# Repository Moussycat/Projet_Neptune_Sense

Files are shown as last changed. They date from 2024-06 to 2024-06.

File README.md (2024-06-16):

# Project_Neptune_Sense

### Projet de synthèse objets connectés

#### Semestre 8 - Option Electronique et Objets connectés ESEO

Notre système se compose de deux modules complémentaires. Il est conçu pour simplifier la gestion de votre espace aquatique tout en garantissant une qualité d'eau optimale

Le premier module, autonome en énergie, est spécialement conçu pour résister aux conditions extérieures. Équipé de capteurs de pointe, il collecte en temps réel les informations essentielles à la bonne gestion de votre piscine. Mesurez avec précision le pH de l'eau, sa température ainsi que celle de l'air ambiant, pour une expérience de baignade toujours agréable. De plus, ce module est doté d'un indicateur de niveau de batterie, vous assurant ainsi une utilisation continue et sans souci.

Le second module, alimenté par le secteur, est votre station de base. Il reçoit et traite toutes les données transmises par le module extérieur. Grâce à son interface intuitive, accédez facilement à toutes les informations relatives à votre piscine, et ce, en un seul endroit.

Ce projet, alliant technologie et praticité, vous offre une solution pour une gestion simplifiée de votre piscine ou bassin.

## Description

Pour que vous puissiez mieux appréhender la logique et les choix qui ont guidé notre projet, nous vous fournissons quelques éléments d'information essentiels. Parmi ces documents, se trouve le [cahier des charges](Cahier_des_charges.pdf) qui définit les objectifs, les contraintes et les exigences auxquelles notre projet doit répondre ainsi que le [schéma synoptique](Schema_synoptique_Neptune_Sense.pdf), qui présente de manière graphique l'ensemble des systèmes pour une vue générale du projet.

### [Code](Code/README.md)

#### [Station de base](Code/main_station_base/)

Cette station s'installe dans un bâtiment où elle pourra avoir accès à un réseau internet. La station permet d'afficher sur un écran TFT la température de l'eau et de l'air, le PH de votre bassin, le niveau de l'eau, le niveau de batterie de la station extérieure, l'horloge et la météo.

#### [Station extérieure](Code/CODE%20NeptuneSense/)

Cette station se met à proximité de votre bassin. La sonde de PH, le capteur de température d'eau et le niveau de l'eau doivent être placé dans l'eau. Le dispositif doit être à proximité d'une station de réception Lora public.

### [PCB](PCB/README.md)

Au cours de notre projet, nous avons élaboré et fabriqué deux cartes de circuits imprimés (PCB) bien distinctes. La première d'entre elles est destinée à la station de base, tandis que la seconde est spécifiquement conçue pour la station extérieure. Il convient de souligner que ces deux PCB sont équipées de microcontrôleurs différents, afin de répondre au mieux aux contraintes et aux exigences de chaque station. Pour en savoir plus sur ce sujet, nous vous invitons à cliquer sur le titre de la partie correspondante.

### [Tests](Tests/README.md)

Nous avons procédé à la réalisation de tests unitaires pour chacune des fonctions implémentées dans les deux stations. Ces tests ont pour objectif de vérifier le bon fonctionnement de chaque fonctionnalité de manière isolée. Les détails et les descriptions de ces tests sont disponibles dans les dossiers respectifs de chaque test, afin de faciliter la compréhension et la traçabilité des vérifications effectuées.

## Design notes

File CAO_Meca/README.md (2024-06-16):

# CAO 

### Station Exterieure :

Nous avons confectionner un socle pouvant acceuilir le PCB et laisser place à tous les parts tels que l'USB C, le port du capteur PH etc.

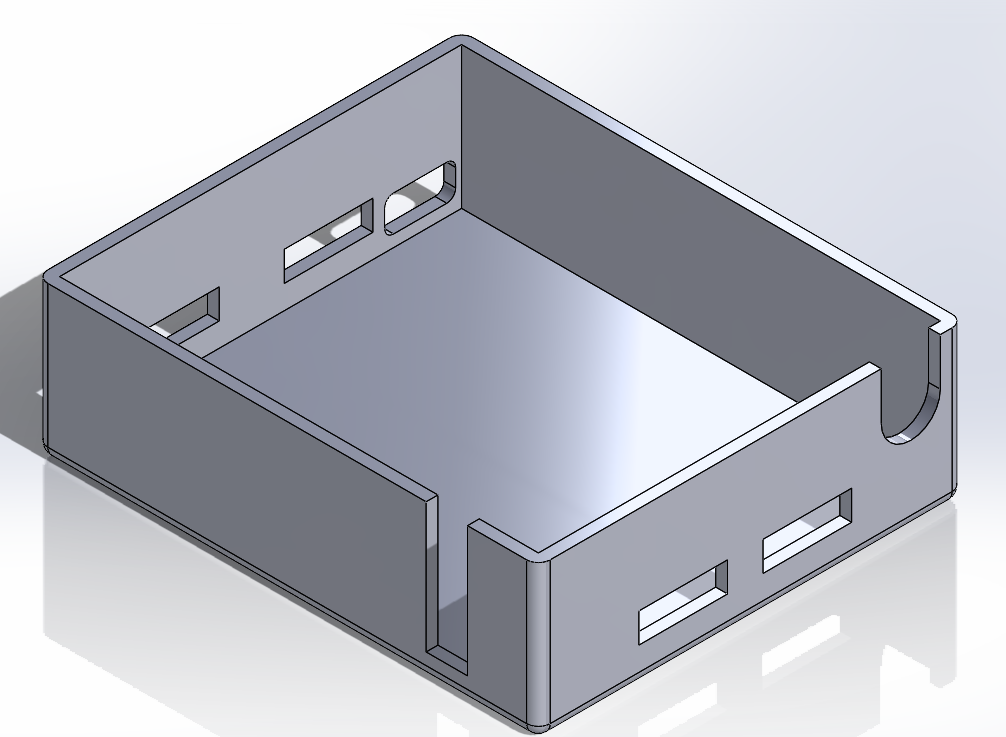
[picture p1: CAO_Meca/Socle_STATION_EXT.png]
Screen image_socle_station_ext


Ainsi le couvercle ne gère que la partie "IHM" avec les leds et boutons.

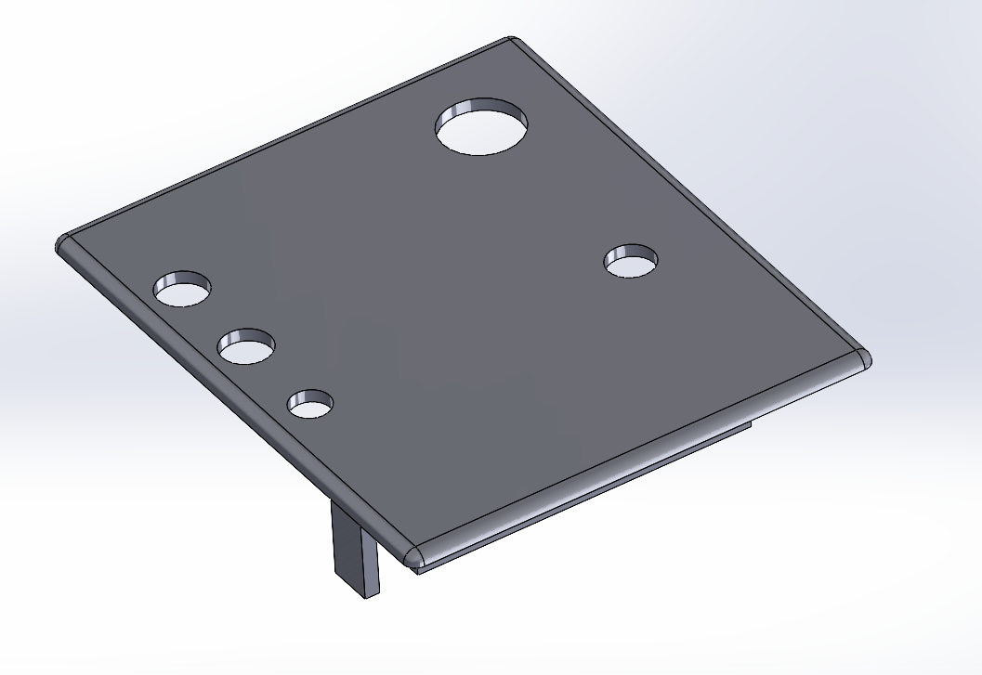
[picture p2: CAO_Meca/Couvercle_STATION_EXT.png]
Screen image_couvercle_station_ext


Voici le résultat réel obtenu :

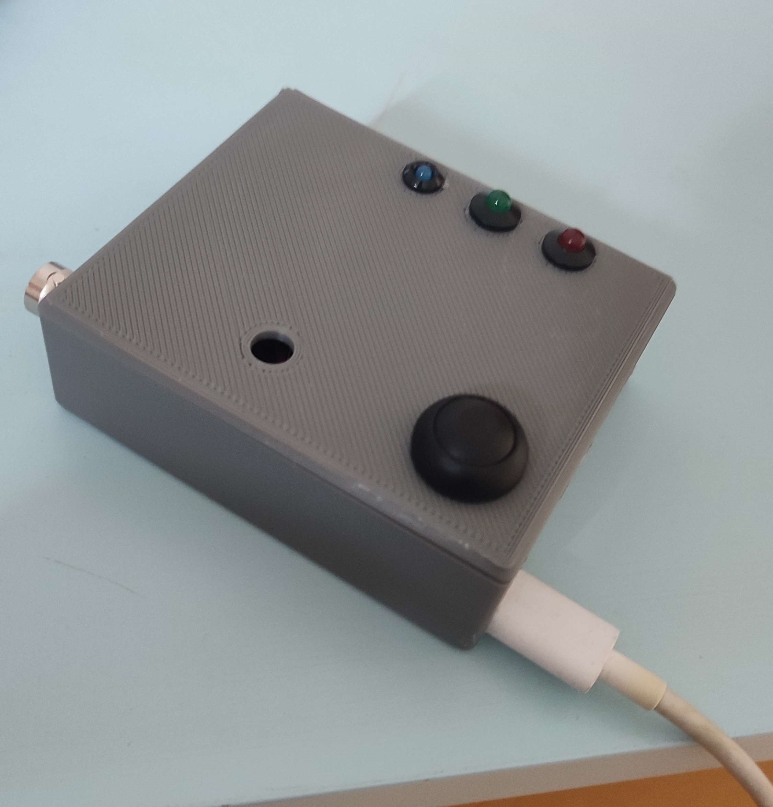
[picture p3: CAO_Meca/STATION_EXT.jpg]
Screen image_reelle_station_ext


Cependant, des changements sont à prendre en compte pour une nouvelle réalisation :
- Prise en compte de la taille de la batterie
- Faire des supports pour surélever légèrement le PCB
- Prévoir une fermeture du boîtier
- Agrandir la taille de la boite pour que les câbles reliés aux borniers ne se coupent pas
- Éviter le plus possible les endroits où l'eau pourrait l'infiltrer (trous)
- Mettre en place un système de fixation pour les panneaux solaires
- Mettre une épaisseur de boîtier plus importante pour plus de résistance

### Station de Base :
Nous avons reéalisé un boitier avec son couvercle avec le logiciel FreeCad.

Pour ce boitier, nous avons prévu un trou pour permettre de brancher un cable USB-C à la PCB. la PCB est aussi fixé grâce à des vises sur des socles prévus à cette effet. 

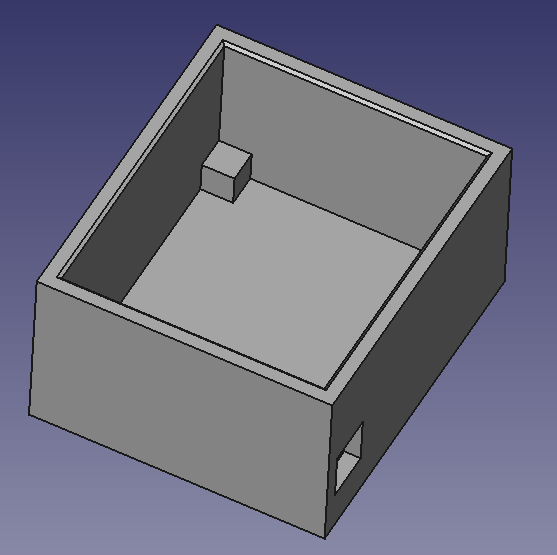
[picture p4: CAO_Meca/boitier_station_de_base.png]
Screen image_reelle_station_ext


Sur le couvercle, il y a un trou qui permet d'accueillir l'écran TFT. L'écran est collé au couvercle. 

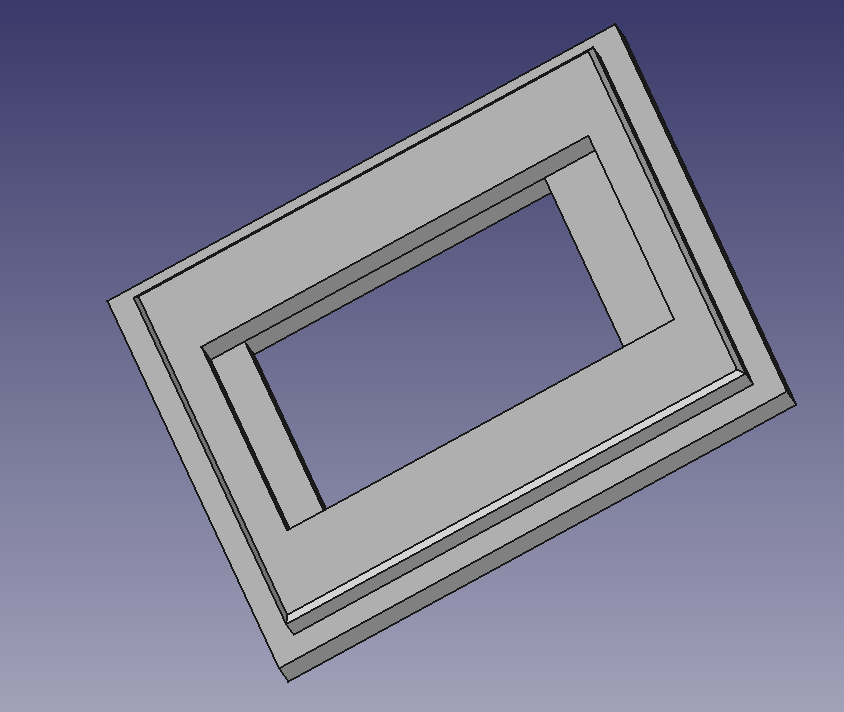
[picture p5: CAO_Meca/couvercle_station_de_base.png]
Screen image_reelle_station_ext


Le boitier est remplie à 15% de matière.

Cependant, des changements sont à prendre en compte pour une nouvelle réalisation :
- prévoir de visé l'écran au couvercle 
- prévoir des trous pour les leds
- ajuster le trou pour L'USB-C

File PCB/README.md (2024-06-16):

# README PCB

## Réalisation des PCB

Dans le cadre de notre projet, nous avons conçu et réalisé deux cartes de circuits imprimés (PCB) distinctes. La première est destinée à la station de base, tandis que la deuxième est dédiée à la station extérieure. Il est important de noter que ces deux PCB ne sont pas équipées du même microcontrôleur.

Pour concevoir et fabriquer nos cartes de circuits imprimés (PCB), nous avons fait appel au logiciel `Altium Designer (23.0.1)`, qui nous a fourni les outils et les fonctionnalités nécessaires à la réalisation de notre projet. Nous nous sommes également inspirés de divers projets disponibles en ligne et des fiches techniques (datasheets) fournies par les fabricants de composants, afin de disposer de toutes les informations et les bonnes pratiques requises. Grâce à ces éléments ainsi qu'à la réalisation de tests rigoureux, nous avons pu aboutir aux rendus présentés ci-dessous.

### Station de base

Pour la station de base, nous avons sélectionné le microcontrôleur `ESP32 WROOM WiFi` par Espressif. Ce choix s'est imposé naturellement, car ce composant intègre directement la connectivité WiFi. Ainsi, il nous est possible de réaliser facilement les requêtes MQTT (Message Queuing Telemetry Transport) indispensables pour récupérer les informations en provenance de la station extérieure. Cette configuration nous permet de centraliser et de traiter efficacement les données collectées.

Dimensions: 76mm x 84mm

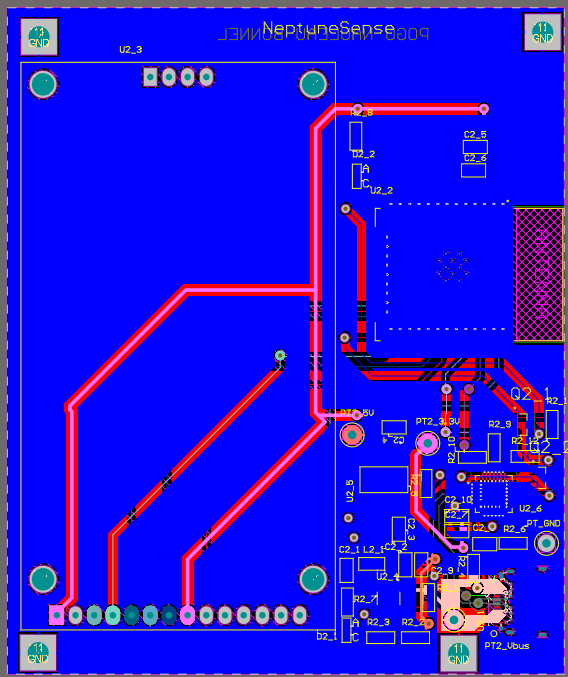
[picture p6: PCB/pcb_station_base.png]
PCB station de base

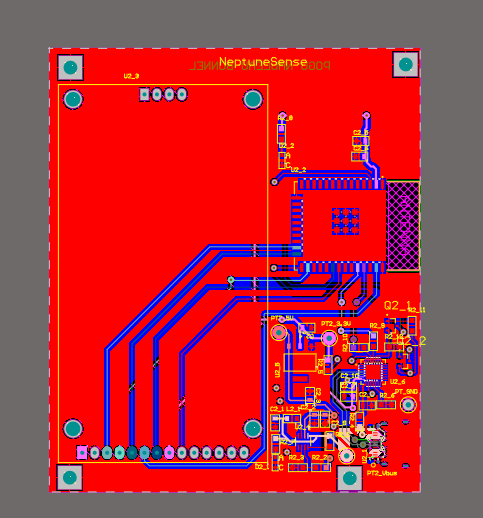
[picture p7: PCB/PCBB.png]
PCB station base top

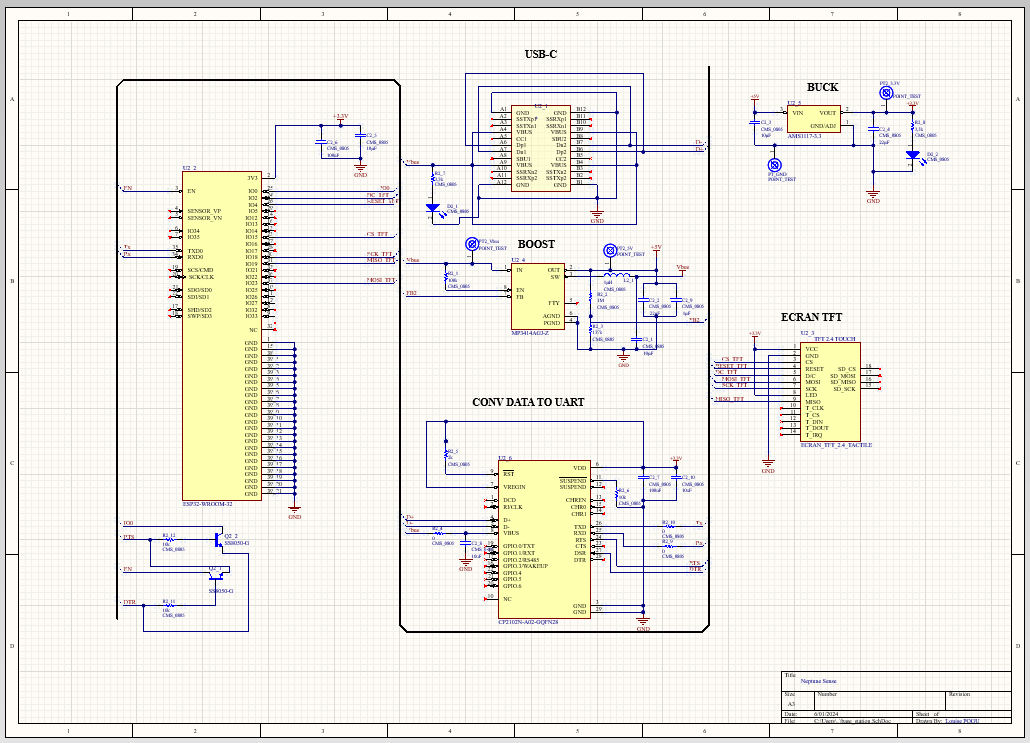
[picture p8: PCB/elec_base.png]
schema elec base


### Station Extérieure

En ce qui concerne la station extérieure, nous avons opté pour un microcontrôleur différent, le `Woi-E5`. Ce dernier est également utilisé dans la STM32WL55JC1 de chez STMicroelectronics. Le choix du Woi-E5 s'est principalement basé sur le fait qu'il intègre la technologie de communication LoRa (Long Range). Cela nous permet de mettre en œuvre le protocole de communication LoRaWAN (Long Range Wide Area Network), essentiel pour assurer des transmissions de données entre la station extérieure et la station de base, via d'autres intermédiaires.

Dimensions: 66mm x 79mm

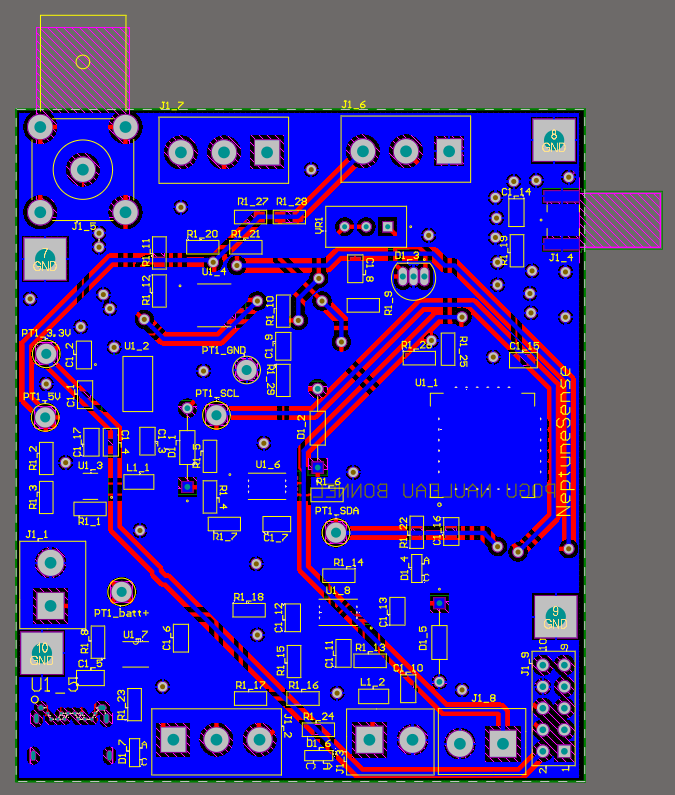
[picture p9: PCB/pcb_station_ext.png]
PCB station ext bot

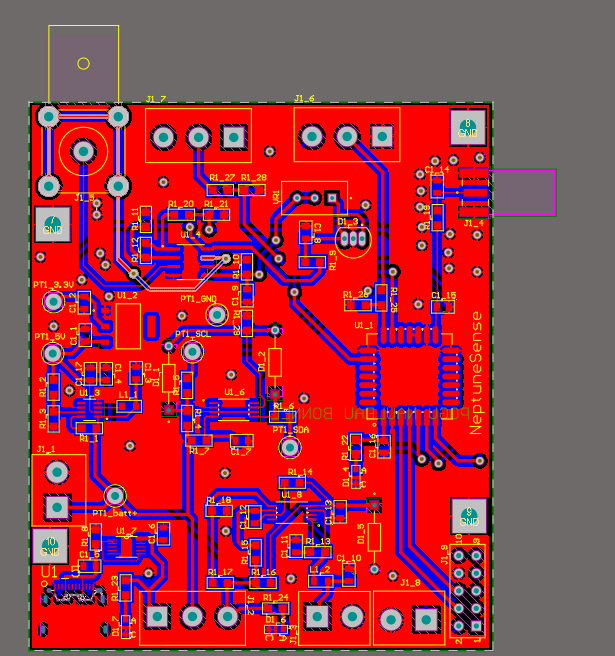
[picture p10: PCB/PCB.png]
PCB station ext top

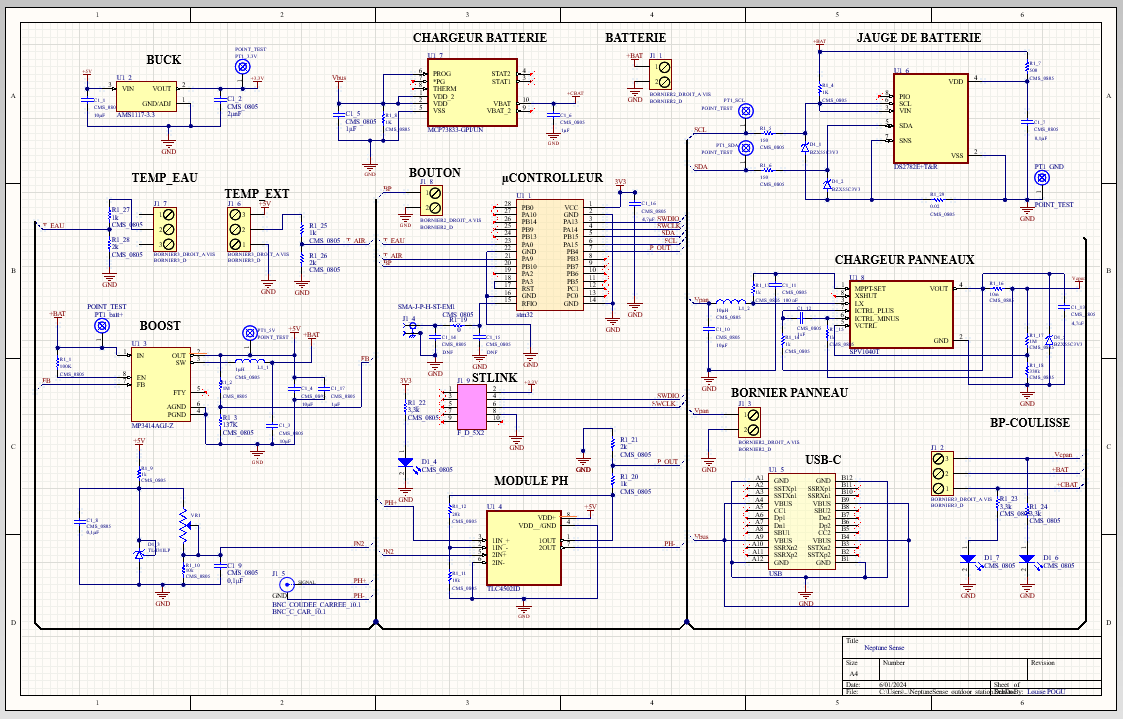
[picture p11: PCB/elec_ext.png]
schema elec ext


## BOM

#### Station Extérieure

- [x] [WIO E5](https://www.digikey.fr/en/products/detail/seeed-technology-co-ltd/114993120/21526009)
      (Footprint locale)

- [x] [USB C](https://my.rs-online.com/web/p/usb-connectors/8950556) (Footprint locale)

- [x] [Capteur de coulombs](https://www.snapeda.com/parts/DS2782E+T/Analog%20Devices/view-part/)
      [(Footprint)](https://www.snapeda.com/parts/DS2782E+T/Analog%20Devices/view-part/)

- [x] [BOOST 5V](https://www.digikey.fr/en/products/detail/monolithic-power-systems-inc/MP3414AGJ-Z/7361472) [(Footprint)](https://www.snapeda.com/parts/MP3414AGJ-Z/Monolithic%20Power/view-part/?ref=search&t=MP3414AGJ-Z)

- [x] [BUCK 3,3v](https://www.digikey.fr/en/products/detail/evvo/AMS1117-3-3/22482148) [(Footprint)](https://www.snapeda.com/parts/AMS1117-3.3/ams%20AG/view-part/?ref=search&t=AMS1117-3.3)

- [x] [Chargeur batterie](https://fr.rs-online.com/web/p/gestion-de-batterie/1459049?gb=s) [(Footprint)](https://www.snapeda.com/parts/MCP73833-GPI/UN/Microchip%20Technology/view-part/?ref=search&t=MCP73833)

- [x] [Chargeur batterie panneau](https://fr.farnell.com/stmicroelectronics/spv1040t/chargeur-batterie-1-8a-tssop-8/dp/2762710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|pcrid|650744400677|plid||kword||match||slid||product||pgrid|103549817689|ptaid|dsa-915064991216|&gad_source=1&gclid=CjwKCAjw5v2wBhBrEiwAXDDoJeK70DMSvAA7zcqXjeuBuuEcbRkl4ev_gvYKbHYqu8RgpD7hmsAmjRoCjAkQAvD_BwE)

- [x] [Bouton poussoir](https://fr.rs-online.com/web/p/boutons-poussoirs/7346704)

- [x] [Interrupteur alim](https://fr.rs-online.com/web/p/interrupteurs-a-bascule/7932563)

- [x] [Interrupteur mode charge](https://fr.rs-online.com/web/p/interrupteurs-a-levier/0394459)

- [x] [Antenne LORA](https://fr.rs-online.com/web/p/antennes-multi-bandes/1248675?gb=s)

- [x] [Port SMA Femelle](https://fr.rs-online.com/web/p/connecteurs-coaxiaux/5265785)[(Footprint)](https://www.snapeda.com/parts/SMA-J-P-H-ST-EM1/Samtec/view-part/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)

- [x] [Batterie 3,7v 2,6A](https://fr.rs-online.com/web/p/piles-rechargeables-taille-speciale/7887261?gb=s)

- [x] [Support batterie](https://www.digikey.fr/en/products/detail/mpd-memory-protection-devices/BH-18650-W/3029217)

- [x] [Capteur de Température externe](https://fr.rs-online.com/web/p/kits-et-cartes-compatibles-arduino/2163753?gb=s)

- [x] [Voyant LED rouge](https://fr.rs-online.com/web/p/indicateurs-pour-montage-panneau/0206845)

- [x] [Voyant LED vert](https://fr.rs-online.com/web/p/indicateurs-pour-montage-panneau/0206867)

- [x] [Voyant LED bleu](https://fr.rs-online.com/web/p/indicateurs-pour-montage-panneau/7239696)

- [x] [Diode Zener](https://fr.rs-online.com/web/p/references-de-tension/0810289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)

- [x] [AOP](https://fr.rs-online.com/web/p/amplificateurs-operationnels/3569782?gb=s)

- [x] [Potentiomètre](https://fr.rs-online.com/web/p/potentiometres-trimmer/5219647)

#### Station de base

- [x] Ecran TFT
- [ ] [ESP32](https://fr.rs-online.com/web/p/modules-wlan/1697594?searchId=394d8d28-7d02-4260-93f3-ee557f2650ac&gb=s)

## Liste des composants

### CMS

- [x] Inductance 10uH (x1)
- [x] Inductance 1uH (x2)
- [x] Condensateur 0.1uF (x3)
- [x] Condensateur 1uF (x4)
- [x] Condensateur 4,7uF (x2)
- [x] Condensateur 10uF (x8)
- [x] Condensateur 22uF (x2)
- [x] Condensateur 100nF (x3)
- [x] Résistance 10m (x1)(Flo)
- [x] Résistance 150 (x2)
- [x] Résistance 500 (x2)
- [x] Résistance 1k (x10)
- [x] Résistance 2k (x3)
- [x] Résistance 3,3k (x5)
- [x] Résistance 10k (x2)
- [x] Résistance 20k (x1)
- [x] Résistance 100k (x2)
- [x] Résistance 137k (x2)
- [x] Résistance 330k (x1)
- [x] Résistance 1M (x3)
- [x] Diode Zener (x3)
- [x] Diode TL431 (x1)
- [x] Led (x6)
- [x] Résistance variable (x1)

### STATION EXTERIEURE :

#### Chargeur panneau

- Inductance 10uH (x1)
- Condensateur 10uF (x1)
- Condensateur 100nF (x1)
- Condensateur 1uF (x1)
- Condensateur 4,7uF (x1)
- Résistance 1k (x3)
- Résistance 10m (x1)
- Résistance 1M (x1)
- Résistance 330k (x1)
- Diode Zener (x1)

#### Module PH

- Résistance 20k (x1)
- Résistance 10k (x1)
- Résistance 1k (x1)
- Condensateur 0.1uF (x2)
- Diode TL431 (x1)

#### Boost

- Résistance 100k (x1)
- Résistance 1M (x1)
- Résistance 137k (x1)
- Condensateur 10uF (x2)
- Inductance 1uH (x1)

#### Buck

- Condensateur 10uF
- Condensateur 22uF

#### Chargeur batterie

- Résistance 1k (x1)
- Condensateur 1uF (x1)

#### Jauge batterie

- Résistance 150 (x2)
- Résistance 500 (x1)
- Résistance 1k (x1)
- Condensateur 0.1uF (x1)
- Diode Zener 3,3v(x2)

### STATION DE BASE :

#### ESP32

- Résistance 3,3k (x2)
- Condensateur 100nF (x1)
- Condensateur 10uF (x1)
- Led (x2)

#### Boost

- Résistance 100k (x1)
- Résistance 1M (x1)
- Résistance 137k (x1)
- Condensateur 10uF (x2)
- Inductance 1uH (x1)

#### Buck

- Condensateur 10uF
- Condensateur 22uF

#### Conv data to uart

- Résistance 1k (x1)
- Résistance 10k (x1)
- Condensateur 100nF (x1)

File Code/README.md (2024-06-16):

# Codes du projet

Le code du projet est divisé en 2 car il y a un code par station.

Dans chaque dossier, vous trouverez la configuration, le but du code réalisé et les différentes parties du code développé.

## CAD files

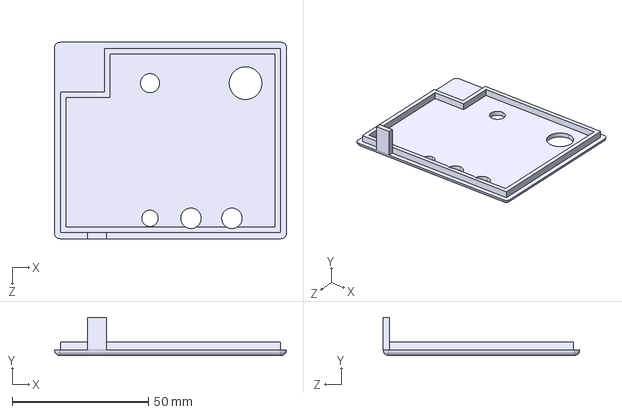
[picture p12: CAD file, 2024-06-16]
CAO_Meca/COUVERCLE STATION EXT.STEP
85.0 x 14.0 x 72.0 mm

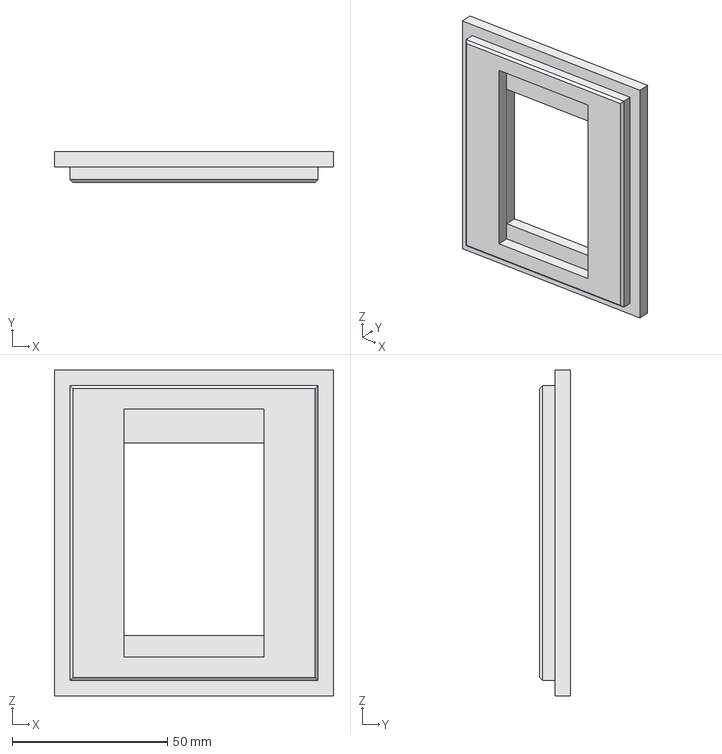
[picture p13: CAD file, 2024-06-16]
CAO_Meca/fichier 3D station de base.FCStd
90.0 x 10.0 x 105.0 mm

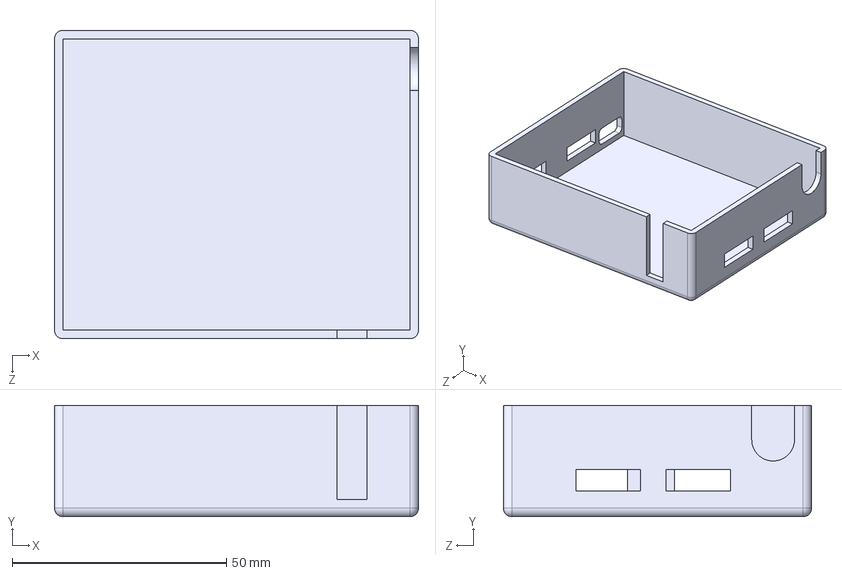
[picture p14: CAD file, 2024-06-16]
CAO_Meca/BOITIER STATION EXT.STEP
85.0 x 26.0 x 72.0 mm

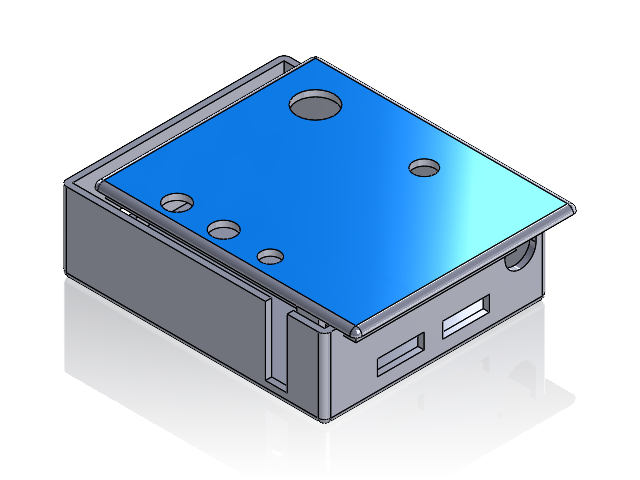
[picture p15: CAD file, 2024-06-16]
CAO_Meca/Assemblage STATION EXT.SLDASM
COUVERCLE STATION EXT
BOITIER STATION EXT

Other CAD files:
CAO_Meca/BOITIER STATION INT.step
CAO_Meca/BOITIER STATION EXT.SLDPRT
CAO_Meca/COUVERCLE STATION EXT.SLDPRT

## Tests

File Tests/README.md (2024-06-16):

# Tests

> [!NOTE]
> Pour chaque dossier de test de composant se trouve:
>
> - Le code fonctionnel de test
> - La configuration du test (Pin, matériel, ...)
> - Les résultats attendus et ceux obtenus (carte de dev et carte finale)
> - Le support visuel (oscilloscope)

- [Test bouton poussoir](Tests/BP_prise_de_mesure/bp_prise_de_mesure.md)
- [Test écran TFT](Tests/Ecran_TFT_SD/readme.md)
- [Test jauge de batterie](Tests/Jauge_batterie/readme.md)
- [Test led](Tests/Leds/readme.md)
- [Test LoraWAN](Tests/Lora_WAN/readme.md)
- [Test panneaux solaires](Tests/Panneaux_solaires/readme.md)
- [Test requête MQTT](Tests/Requete_MQTT/readme.md)
- [Test sonde PH](Tests/Sonde_PH/README.md)
- [Test sonde température de l'air](Tests/Sonde_temp_air/README.md)
- [Test sonde température de l'eau](Tests/Sonde_temp_eau/README.md)

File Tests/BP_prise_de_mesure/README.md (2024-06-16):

# Test Bouton prise de mesure

## Matériel utilisé

- Bouton poussoir

#### Carte STM32 & carte finale

- STM32WL
- STM32 IDE

## Pins

#### Carte STM32WL55

| STM32 PIN | Bouton poussoir |
| :---: | :---: |
| PA11 | 1 |
| 5V | 2 |

#### Carte finale

| Carte finale PIN | Bouton poussoir |
| :---: | :---: |
| PB10 | 1 |
| 5V | 2 |

## Les résultats attendus

#### Carte STM32, carte finale

Lors de l'appui sur le bouton, on réalise une prise de mesure en manuel pour forcer la prise d'information.

## Les résultats obtenus

On prend bien les informations uniquement lorsque l'on appuie sur le bouton poussoir

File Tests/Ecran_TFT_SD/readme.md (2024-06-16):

# Test Ecran TFT

## Matériel utilisé

#### Carte ESP32 & carte finale

- ESP32 WROOM WIFI
- Arduino IDE
- Ecran TFT

## Configuration logiciel

#### Carte ESP32 & carte finale

Utilisation du logiciel Arduino IDE pour envoyer le code.

## Pins

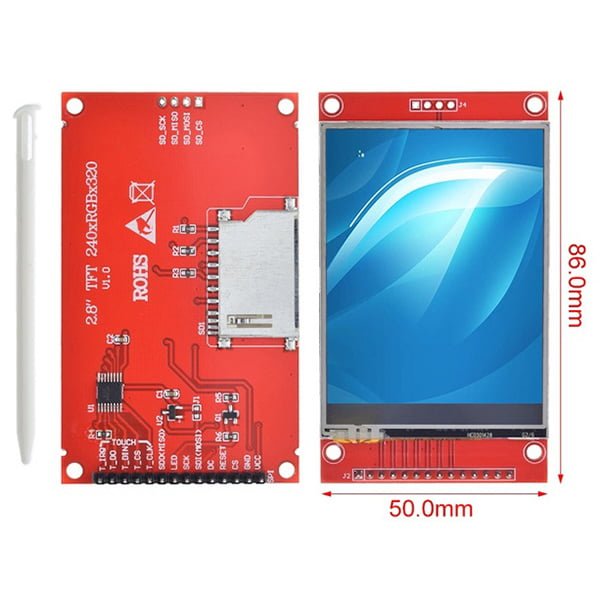
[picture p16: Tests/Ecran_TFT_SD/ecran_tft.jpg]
Screenshot pinout


#### Carte ESP32 & carte Finale

| ESP32 PIN | Ecran TFT |
| :---: | :---: |
| 3,3V | VCC |
| GND | GND |
| D15 | CS |
| D4 | RESET |
| D2 | DC |
| D23 | MOSI |
| D18 | SCK |
| 3,3V | LED |
| D19 | MISO |

## Les résultats attendus

#### Carte ESP32, carte finale

On envoie des données d'affichage sur l'écran. On doit obtenir sur l'écran les données envoyées.

## Les résultats obtenus

On obtient bien le bon affichage par rapport au code envoyé.
Screenshot affichage

En orange se trouve la trame SCK (D18) et en vert la trame CS (D15).
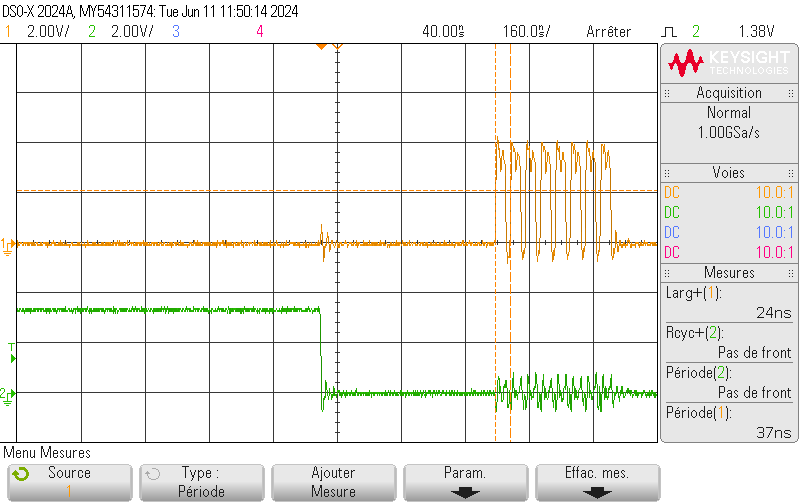
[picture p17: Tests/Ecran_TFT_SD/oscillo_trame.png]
Oscillo_trame


En vert nous observons la trame MOSI (D23)
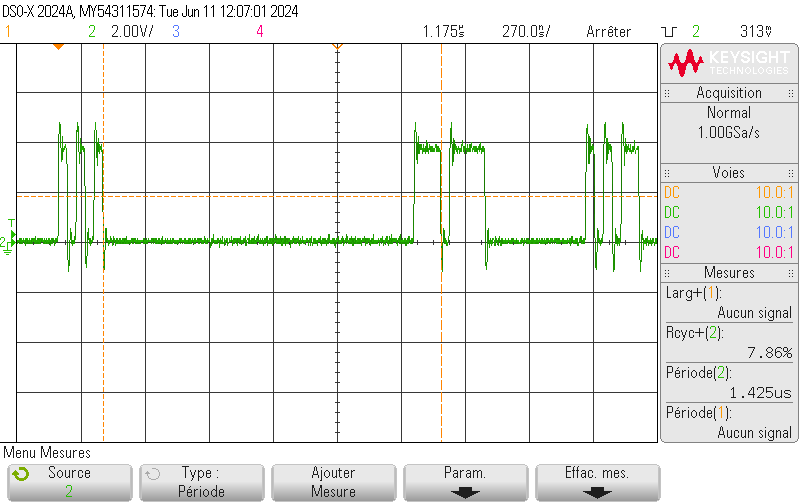
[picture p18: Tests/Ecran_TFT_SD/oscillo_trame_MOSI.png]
Oscillo_trame_MOSI


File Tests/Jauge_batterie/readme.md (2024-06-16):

# Test Jauge de batterie

## Matériel utilisé

- Jauge de batterie
- Batterie
-

#### Carte ESP32

- ESP32 WROOM
- IDE Arduino
-

#### Carte STM32 & carte finale

- STM32WL
- IDE ARduino

#### ATTENTION : Bien changer la capacité en mAh de la batterie dans le code ici par exemple 1050mAh :

MAH

### Port I2C :

- GND: Broche d'alimentation, à connecter au système GND
- VCC: Broche d'alimentation, connectée à l'alimentation 5V ou 3,3V de ce module.
- SDA : Broche de signal, données série I2C
- SCL: Broche de signal, horloge série I2C

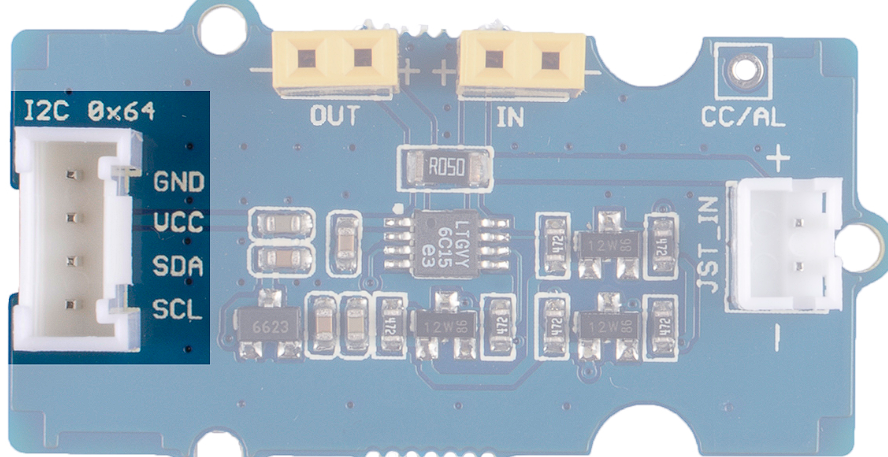
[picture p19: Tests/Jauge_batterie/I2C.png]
Port I2C


### Port OUT :

- Sortie d'alimentation, connexion à la charge ou au chargeur.
- +: Puissance de sortie Électrode positive
- -: Puissance de sortie de l'électrode négative

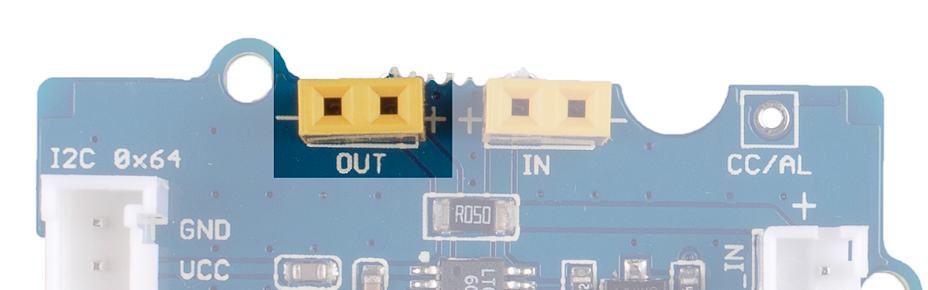
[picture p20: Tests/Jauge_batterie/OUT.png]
Port OUT


### Port IN :

- Entrée d'alimentation, alimentation de la sortie
- - : Entrée d'alimentation Électrode positive
- - : Électrode négative de l'entrée d'alimentation

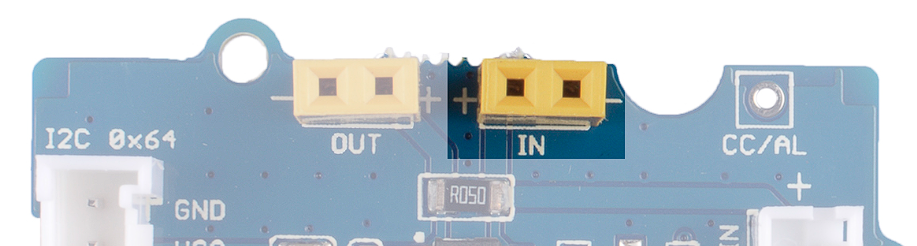
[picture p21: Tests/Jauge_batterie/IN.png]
Port IN


### Port BATTERIE :

- Entrée batterie, supporte une batterie Li-PO de 3,7-4,2v,
- Jst2.0(2 pin-2.0mm), alimentation de la sortie.

- - : Entrée de la batterie Electrode positive
- - : Électrode négative de l'entrée de la batterie

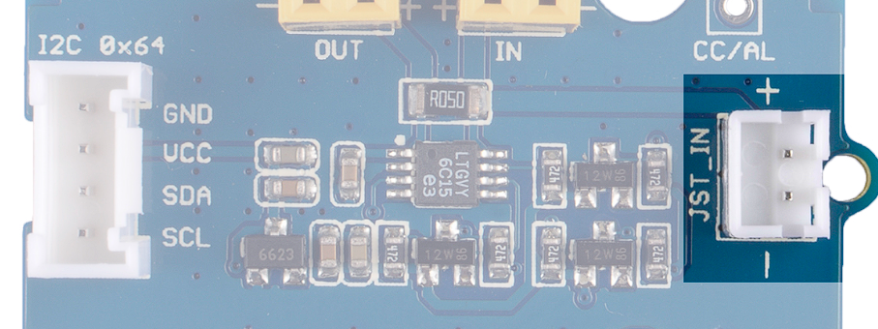
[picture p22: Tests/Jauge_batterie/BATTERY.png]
Port Battery


## Configuration

Voici le montage utilisé pour faire le test à la différence que la batterie est remplacée par une alimentation. Au niveau du code nous avons configuré pour une batterie de 1050mAh pour l'exemple.

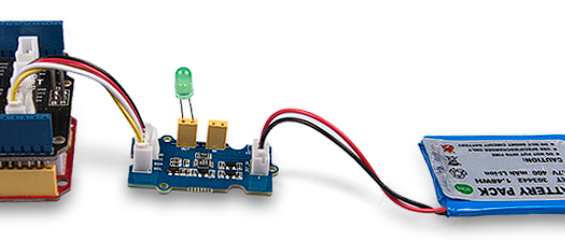
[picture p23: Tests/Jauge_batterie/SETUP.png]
SETUP


## Les résultats attendus

Nous devons recevoir sur le terminal le pourcentage de batterie depuis que le compteur de coulomb est alimenté.
Nous nous sommes basés sur le test de [SEEED STUDIO](https://wiki.seeedstudio.com/Grove-Coulomb_Counter_3.3V_to_5V-LTC2941)

## Les résultats obtenus

Ici on récupère bien les données, bien évidemment la capacité n'est pas récaliste puisqu'on utilise pas une vraie batterie.

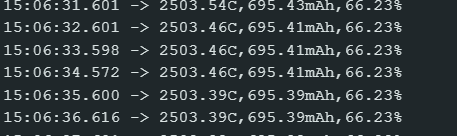
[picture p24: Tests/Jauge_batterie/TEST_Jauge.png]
Test Jauge


#### Trame SCL :

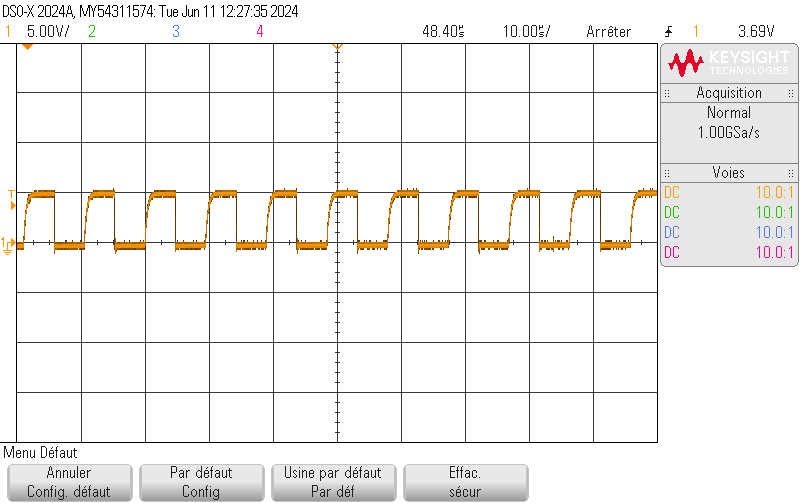
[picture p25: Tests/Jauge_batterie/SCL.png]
Test Jauge


#### Trame SDA :

Test Jauge

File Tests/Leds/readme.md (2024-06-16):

# Test Leds

## Matériel utilisé

#### Carte ESP32

- ESP32 WROOM WIFI
- Arduino IDE
- LED

#### Carte STM32WL55

- STM32WL55
- STM32 IDE
- LED + Résistance

#### Carte finale

##### station extérieure

- STM32WL55
- STM32 IDE
- LED + Résistance

##### station intérieure

- ESP32 WROOM WIFI
- Arduino IDE
- LED + Résistance

## Pins

#### Carte ESP32 WROOM

| ESP32 WROOM Pin | LED |
| :---: | :-: |
| GND |  -  |
| GPIO 26 |  +  |

## Les résultats attendus

#### Carte ESP32, STM32WL55, carte finale (station de base et station extérieure)

on arrive à allumer la deuxième led de la carte nucléo.

## Les résultats obtenus

#### Carte ESP32

On a bien le changement d'état de la led jaune avec la trame.
OK led
OK oscillo

#### Carte STM32WL55

On a bien le changement d'état de la led verte (en bas de la carte).
Screen ON
On arrive à allumer la led avec la commande initialisation(BSP_LED_Init(LED3)) puis la commande (BSP_LED_Toggle(LED3))

cela utilise c'est ligne de comande :

```
  GPIO_InitTypeDef GPIO_InitStructure;
  GPIO_InitStructure.Pin = GPIO_PIN_3;
  GPIO_InitStructure.Mode = GPIO_MODE_OUTPUT_PP;
  GPIO_InitStructure.Pull = GPIO_NOPULL;
  GPIO_InitStructure.Speed = GPIO_SPEED_FREQ_HIGH;
  HAL_GPIO_Init(GPIOB, &GPIO_InitStructure);
  HAL_GPIO_WritePin(GPIOB, GPIO_PIN_3, GPIO_PIN_SET);
```

#### Carte finale

##### station extérieure

testledbleue

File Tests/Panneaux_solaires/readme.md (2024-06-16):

# Test Panneaux solaires

## Matériel utilisé

- Multimètre
- Panneau solaire
- Soleil

## Les résultats attendus

Lorsque l'on met le panneau au soleil aux bornes du panneau, nous devons avoir une tension d'environ +5,5V (selon la datasheet).

## Les résultats obtenus

On obtient bien une tension d'environ +5,5V, le panneau fonctionne correctement.

Screen test

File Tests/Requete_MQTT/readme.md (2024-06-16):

# Test Requête MQTT

## Matériel utilisé

#### Carte ESP32

- ESP32 WROOM WIFI
- Arduino IDE

#### Carte finale

##### station de base

- ESP32 WROOM
- Arduino IDE

## Configuration logiciel

#### Carte Arduino UNO & carte finale

Utilisation du logiciel Arduino IDE, ne pas oublier d'ajouter le ssid et mot de passe dans le code pour ajouter un réseau WiFi.

## Les résultats attendus

#### Carte ESP32 & carte finale

1- Le code doit scruter tous les réseaux enregistrés dans le code et se connecter au réseau disponible.

2- Envoi d'un message via un MQTT broker public. Lorsque j'envoie un message, l'ESP32 doit recevoir le message et l'afficher.

## Les résultats obtenus

> [!WARNING]
> Pour utiliser votre Iphone comme point d'accès, n'oubliez pas de cocher la case "Maximiser la compatibilité". Sans cette activation, la connexion ne pourra se faire.

#### Carte ESP32

1- Connexion entre un point d'accès téléphone et box internet réussi.

Screen Wifi OK

2- Le message est bien affiché.

Screen MQTT broker

#### Carte finale

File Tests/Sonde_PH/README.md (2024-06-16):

# Test Sonde de Ph

## Matériel utilisé

#### Carte Arduino UNO

- Arduino UNO
- Arduino
- Sonde de Ph

#### Carte STM32WL55 & carte finale

- STM32WL55
- Arduino
- Sonde de Ph

## Configuration logiciel

#### Carte Arduino UNO

utilisation du logiciel Arduino

#### Carte STM32WL55 & carte finale

utilisation du logiciel Arduino avec STM32CubeProgrammer

## Pins

#### Carte Arduino UNO

| Arduino UNO Pin | Sonde de Ph Pin |
| :---: | :---: |
| GND | GND |
| 5V | VCC |
| A0 | Data |

#### Carte STM32WL55 & carte finale

| STM32WL55 Pin | Sonde de Ph Pin |
| :---: | :---: |
| GND | GND |
| 5V | VCC |
| PB4 | Data |

## Les résultats attendus

#### Carte Arduino UNO, STM32WL55, carte finale

Lorsque l'on plonge la sonde dans de l'eau du robinet, la valeur doit être à 7.

## Les résultats obtenus

#### Carte Arduino UNO

Voici le montage que l'on a utilisé pour tester la sonde PH avec une arduino UNO.

Screenshot Test variation

Les resultats obtenues lors de ce test sont des valeurs de pH proche de la valeur attendue.

Screenshot Test variation

### Carte STM32WL55

Voici le montage que l'on a utilisé pour tester la sonde PH avec une nucleo WL55JC1.

Screenshot Test variation

Les resultats obtenues lors de ce test sont des valeurs de pH proche de la valeur attendue.

Screenshot Test variation

### Carte finale

Nous n'avons pas eu le temps de terminé la verification de l'envoi des bonnes infos au microcontrolleurs

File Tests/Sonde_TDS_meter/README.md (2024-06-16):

# Test Sonde TDS

## Matériel utilisé

#### Carte ESP32

- ESP32
- Arduino
- TDS Meter (qualité d'eau)

#### Carte STM32WL55 & carte finale

- STM32WL55
- Arduino
- TDS Meter (qualité d'eau)

## Configuration logiciel

#### Carte ESP32

Sur Arduino, installez les board ESP32

#### Carte STM32WL55 & Carte finale

Sur Arduino, installez les board STM32 .
Installer aussi le logiciel STM32CubeProgrammer

## Pins

#### Carte ESP32

| ESP 32 Pin | TDS Pin |
| :---: | :-----: |
| GND | GND |
| 3.3V | VCC |
| GPIO 27 (ADC pin) |  Data |

#### Carte STM32WL55

| STM32WL55 Pin | TDS Pin |
| :---: | :-----: |
| GND | GND |
| 3V3 | VCC |
| PB2 |  Data |

#### Carte finale (pas prévu sur la PCB)

| Carte final Pin | TDS Pin |
| :---: | :-----: |
| GND | GND |
| 3V3 | VCC |
| PB3 |  Data |

## Les résultats attendus

#### Carte ESP32, STM32WL55, carte finale

> [!IMPORTANT]
> Pour les tests suivants de l'ESP32, l'eau était à une température élevée ( >> 25°C)

Lorsque l'on ne plonge pas la sonde, la valeur doit être de 0ppm et 0,0V.

Lorsque l'on plonge au maximum la sonde, la valeur doit être maximal selon la température de l'eau et de sa qualité.

Lorsque l'on fait varier la hauteur du niveau d'eau sur les deux broche métaliques, la valeur de ppm et de tension doit varier.

## Les résultats obtenus

#### Carte ESP32

Lorsque l'on ne plonge pas la sonde, la valeur de ppm est à 0 ppm et la valeur de la conversion de la valeur de la tension en valeur tds on obtient 0V

Screenshot Test 0V

Lorsque l'on plonge totalement la sonde dans l'eau, on obtient la valeur maximum pour l'eau mesurée.
Screenshot Test max

Lorsque l'on fait varier le niveau de l'eau, on obtient bien une variation des valeurs.

Screenshot Test variation

#### Carte STM32WL55

Lorsque l'on plonge totalement la sonde dans l'eau, on obtient la valeur maximum pour l'eau mesurée et quand on l'enlève, on observe bien un changement de valeur qui se rapproche de la valeur de 0 ppm.

Screenshot Test variation

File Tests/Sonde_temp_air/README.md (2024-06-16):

# Test DHT11

## Matériel utilisé

#### Carte Arduino UNO

- Arduino UNO
- Arduino
- DHT11 (capteur de temperature et d'humidité)

#### Carte STM32WL55 & carte finale

- STM32WL55
- Arduino
- DHT11 (capteur de température et d'humidité)

## Configuration logiciel

#### Carte Arduino UNO

utilisation du logiciel Arduino

#### Carte STM32WL55 & carte finale

utilisation du logiciel Arduino avec STM32CubeProgrammer

## Pins

Screenshot pinout

#### Carte Arduino UNO

| Arduino UNO Pin | DHT11 Pin |
| :---: | :---: |
| GND | GND |
| 3.3V | VCC |
| Pin 2 | Data |

#### Carte STM32WL55 & carte finale

| STM32WL55 Pin | DHT11 Pin |
| :---: | :---: |
| GND | GND |
| 5V | VCC |
| PA9 | Data |

## Les résultats attendus

#### Carte Arduino UNO, STM32WL55, carte finale

lorsque l'on branche le DHT11, on obtient une température constante et un taux d'humitidé

lorsque l'on met un doigt sur le DHT11, on voit une variation de la température (elle augmente).

lorsque l'on enleve le doigt sur le DHT11, on voit une variation de la température (elle diminue).

## Les résultats obtenus

#### Carte Arduino UNO

Lorsque l'on branche la carte arduino connecté au DHT11, on observe qu'on obtient une valeur de température et humidité constante. Cela est bien le résultat attendu.

Screenshot initial

Lorsque l'on met un doigt et on l'enlève , on observe bien un pic de température avec une augmentation quand le doigt est sur le capteur et une diminution de la valeur quand on l'enlève pour retourné à la valeur initial.

Screenshot doigt

#### Carte STM32WL55

Lorsque l'on branche la carte arduino connecté au DHT11, on observe qu'on obtient une valeur de température et humidité constante. Cela est bien le résultat attendu. Et la température varie bien quand on rajoute le doigt.

Screenshot doigt

#### Carte finale

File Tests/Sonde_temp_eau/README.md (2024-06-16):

# Test Sonde de température eau (DS18B20 ou MCP9701)

## Matériel utilisé

#### Carte Arduino UNO

- Arduino UNO
- Arduino
- DS18B20

#### Carte STM32WL55 & carte finale

- STM32WL55
- Arduino
- MCP9701

## Configuration logiciel

#### Carte Arduino UNO

utilisation du logiciel Arduino

#### Carte STM32WL55 & carte finale

utilisation du logiciel Arduino avec STM32CubeProgrammer

## Pins

Screenshot pinout
Screenshot pinout

#### Carte Arduino UNO

| Arduino UNO Pin | DS18B20 Pin |
| :---: | :---: |
| GND | GND |
| 3.3V | VCC |
| P4 | VOUT |

#### Carte STM32WL55

| STM32WL55 Pin | MCP9701 Pin |
| :---: | :---: |
| GND | GND |
| 5V | VCC |
| PB1 | VOUT |

#### Carte finale

| Carte final Pin | DS18B20 Pin |
| :---: | :---: |
| GND | GND |
| 5V | VCC |
| PA0 | VOUT |

## Les résultats attendus

#### Carte Arduino UNO, STM32WL55, carte finale

lorsque l'on branche le DS18B20 ou le MCP9701, on obtient une température constante

lorsque l'on met un doigt sur le DS18B20 ou le MCP9701, on voit une variation de la température (elle augmente).

lorsque l'on enleve le doigt sur le DS18B20 ou le MCP9701, on voit une variation de la température (elle diminue).

## Les résultats obtenus

#### Carte Arduino UNO

Lorsque l'on branche la carte arduino connecté au DS18B20, on observe qu'on obtient une valeur de température constante. Cela est bien le résultat attendu.

Screenshot initial

Lorsque l'on branche la carte arduino connecté au DHT11, on observe qu'on obtient une valeur de température et humidité constante. Cela est bien le résultat attendu. Et la température varie bien quand on rajoute le doigt.

Screenshot doigt

#### Carte STM32WL55

On a utilisé un MCP9701 pour ce test.
Lorsque l'on met un doigt et on l'enlève , on observe bien un pic de température avec une augmentation quand le doigt est sur le capteur et une diminution de la valeur quand on l'enlève pour retourné à la valeur initial.

Screenshot doigt

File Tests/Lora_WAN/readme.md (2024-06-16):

# Test LoRaWAN

## Matériel utilisé

#### Carte STM32 & carte finale

- STM32WL
- STM32 IDE
- TTN

## Les résultats attendus

#### Carte STM32, carte finale

Nous devons nous connecter au TTN, pour pouvoir envoyer des paquets d'informations sur le serveur MQTT pour décoder en partie les trames envoyées

## Les résultats obtenus

#### Premier test d'envoi :

La carte est bien détectée par TTN mais la connexion ne se fait pas.

Screen recuperationok

#### Connexion réussie :

La problème venait de la saisie des appKey et Nwk Key.

Screen CONNEXION

#### Modification des paquets :

Envoi d'une trame avec date et heure dans un JSON. L'app Cayenne n'existant plus, le JSON était la solution la plus efficace.

Screen ENVOI_PACKET

#### Décodeur TTN :

Afin de décoder la trame correctement, il faut configurer le décodeur sur TTN.
Voici le code utilisé avec le résultat décodé.

Screen TEST_DECODER

#### Réception de la trame :

On retrouve dans le JSON envoyé la partie "payload" qui nous intéresse.
Il y a bien "date" et "time" :

Screen PAYLOAD_JSON

Sinon sans même ouvrir nous pouvons directement voir le décodage dans la réception en live :

Screen DECODER_RESULTAT

#### Test Uplink et DownLink manuel :

Afin de s'assurer du bon fonctionnement dans les deux sens. Nous avons fait un test de downlink et uplink en manuel.
Nous avons saisi le port 10, et nous pouvons vérifier le résultat sur TTN :

Screen DOWNLINK_UPLINK_PORT10

La résultat est vérifiable directement sur le port série directement sur l'IDE. Ici il y a bien la réception sur le port 10 :

Screen RECEIVED_PACKET_ON_PORT_10

Ainsi nous sommes assurés du bon fonctionnement du système, nous allons pouvoir utiliser de réelles données de capteurs et ajouter quelques fonctionnalités.

#### Envoi de données des capteurs :

Avec les différents codes déjà testés indépendamment, nous avons pu directement ajouter la prise de mesure et envoyer les données de la même manière.
Ici nous pouvons trouver les résultat de température de l'air, l'humidité, et le ph.

Screen RECEPTION_TRAME_COMPLETE

#### Envoi instantané à l'appui :

Maintenant que la plupart des capteurs fonctionnent, nous pouvons ajouter la fonctionnalité d'envoi instantané. Comme prévu au cahier des charges, il doit être possible d'envoyer instantanément les données lors de l'appui d'un bouton.

En effet le résultat du PH n'est pas cohérent, cela est dû au calcul interne dans le code qui doit être ajusté. Le résultat est bien reçu sur TTN (ici la capture a été faite avant l'ajout du PH) :

Screen PRESS_BOUTON

Dès l'appui, la broche prend le 5V, l'appui est alors détecté. Ensuite les données sont envoyées et l'envoi instantané est confirmé. Une fois cela fait, le cycle habituel reprend.

Gestion d'erreur : si on reste appuyé longtemps cela ne change rien il n'y aura bien qu'une seule trame d'envoyée et non un envoi constant.

#### Gestion led :

Un petit ajout a été effectué afin que la led bleu s'allume à chaque envoi de données, voici le montage final utilisé pour les tests :

Screen MONTAGE

Résultat avec le couvercle 3D :

Screen MONTAGE

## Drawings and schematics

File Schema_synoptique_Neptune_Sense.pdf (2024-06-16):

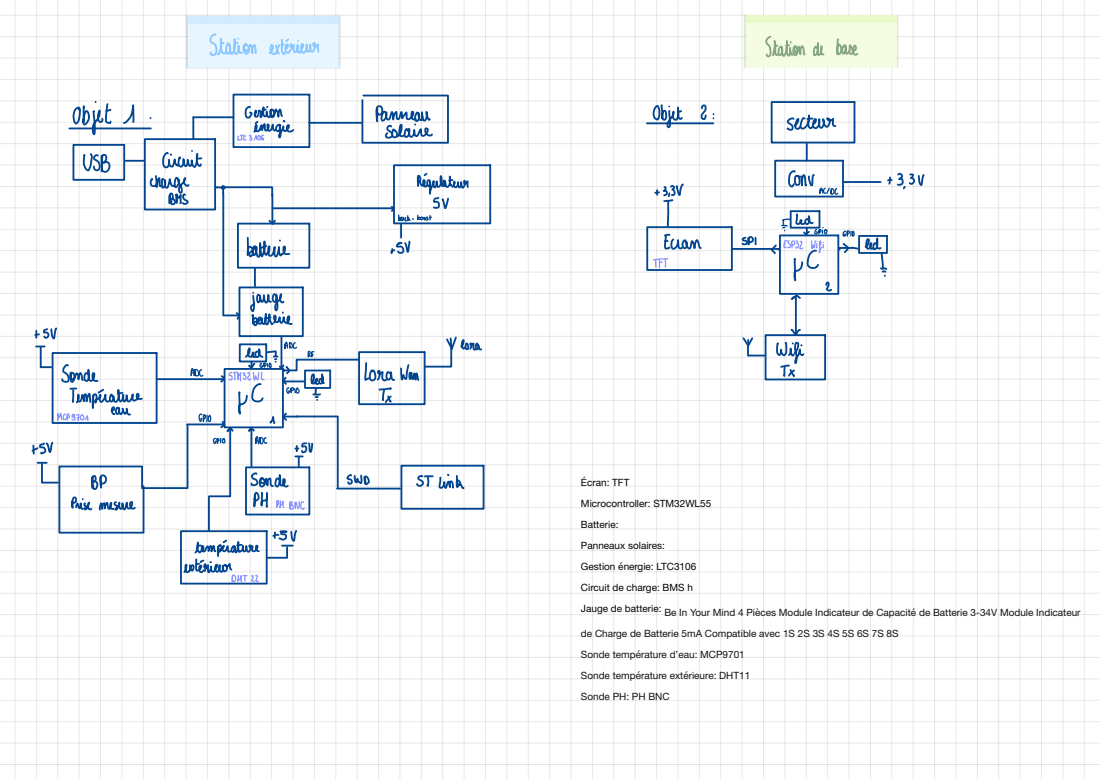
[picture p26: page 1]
i don -E

Écran: TFT
Microcontroller: STM32WL55
Batterie:
Panneaux solaires:
Gestion énergie: LTC3106
Circuit de charge: BMS h
Jauge de batterie: Be In Your Mind 4 Pièces Module Indicateur de Capacité de Batterie 3-34V Module Indicateur

de Charge de Batterie 5mA Compatible avec 1S 2S 3S 4S 5S 6S 7S 8S
Sonde température d’eau: MCP9701
Sonde température extérieure: DHT11
Sonde PH: PH BNC

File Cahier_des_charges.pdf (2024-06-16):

# Neptune Sense

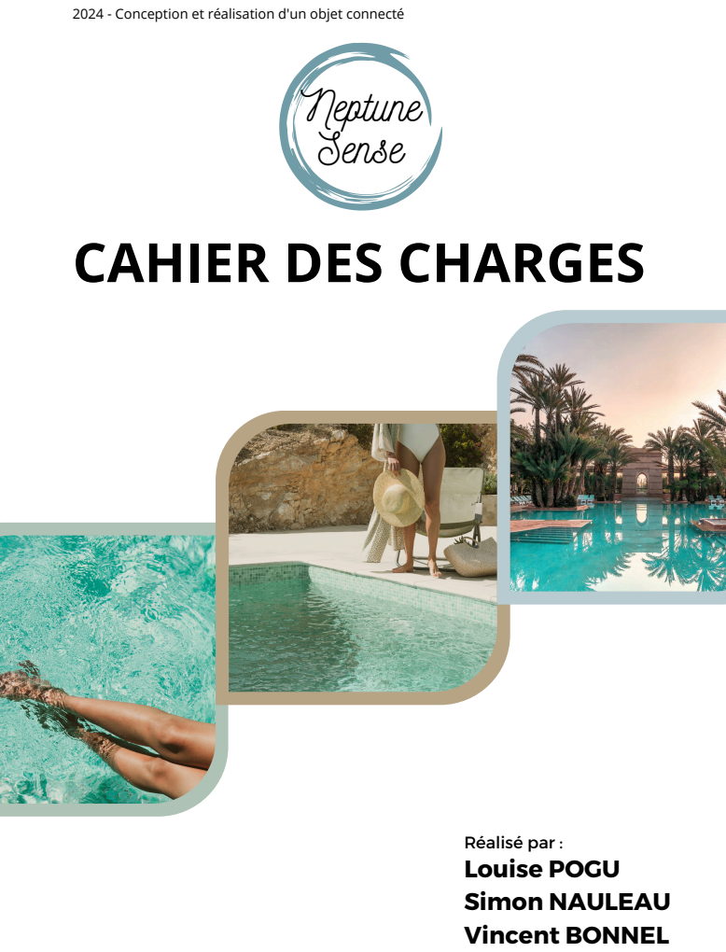
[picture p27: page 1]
Réalisé par : Louise POGU Simon NAULEAU Vincent BONNEL

2024 - Conception et réalisation d'un objet connecté

CAHIER DES CHARGES

# Contexte

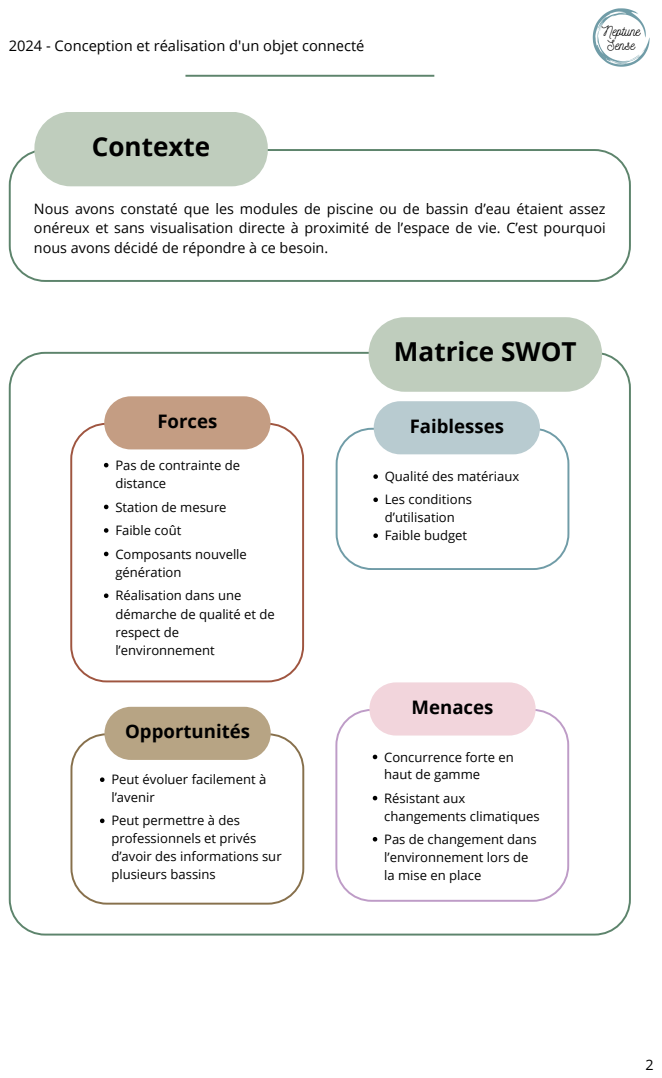
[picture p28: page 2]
Menaces; Opportunités; Matrice SWOT; Forces; Faiblesses; Neptune Sense

Nous avons constaté que les modules de piscine ou de bassin d’eau étaient assez
onéreux et sans visualisation directe à proximité de l’espace de vie. C’est pourquoi
nous avons décidé de répondre à ce besoin.

Pas de contrainte de
distance
Station de mesure
Faible coût
Composants nouvelle
génération
Réalisation dans une
démarche de qualité et de
respect de
l’environnement

Qualité des matériaux
Les conditions
d’utilisation
Faible budget

Concurrence forte en
haut de gamme
Résistant aux
changements climatiques
Pas de changement dans
l’environnement lors de
la mise en place

Peut évoluer facilement à
l’avenir
Peut permettre à des
professionnels et privés
d’avoir des informations sur
plusieurs bassins

# Objectifs

Le besoin utilisateur

Le projet a pour ambition
d’implanter cet objet connecté à la fois pour les besoins particuliers, mais aussi d’entreprise. L’objectif est de concevoir un objet qui puisse renvoyer les informations d’un bassin d’eau que ce soit dans une piscine, mais aussi à l’extérieur comme les bassins agricoles, lacs, etc. La très longue portée du
système | lui | permettrait | de
répondre à ce besoin.

S

Spécifique
Réaliser une station de
base et un module de
mesure pour bassin
M

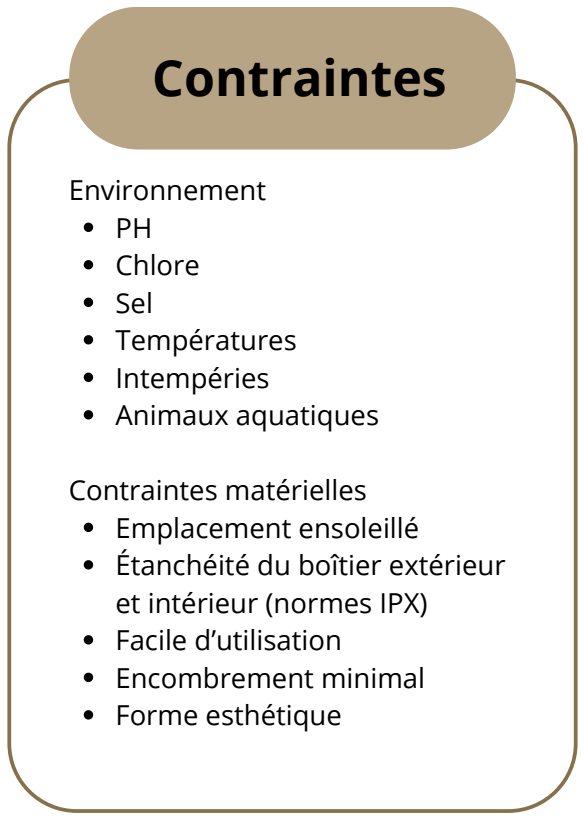
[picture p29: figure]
Contraintes; Environnement PH Chlore Sel Températures Intempéries Animaux aquatiques; Contraintes matérielles Emplacement ensoleillé Étanchéité du boîtier extérieur et intérieur (normes IPX) Facile d’utilisation Encombrement minimal Forme esthétique

A

Mesurable
Une station de base
Un objet connecté
2 prototypes PCB
2 prototypes 3D

R

Atteignable
Prototype fonctionnel
Utilisation de nouvelles
technologies et méthodes

T

Réaliste
Remontée d’informations à
distance, en intérieur
comme extérieur pour
toute application
Temporel
3 mois pour réaliser le
projet
1 jalon par semaine
1 Rapport de fin de projet 1 poster

Diagramme prévisionnel

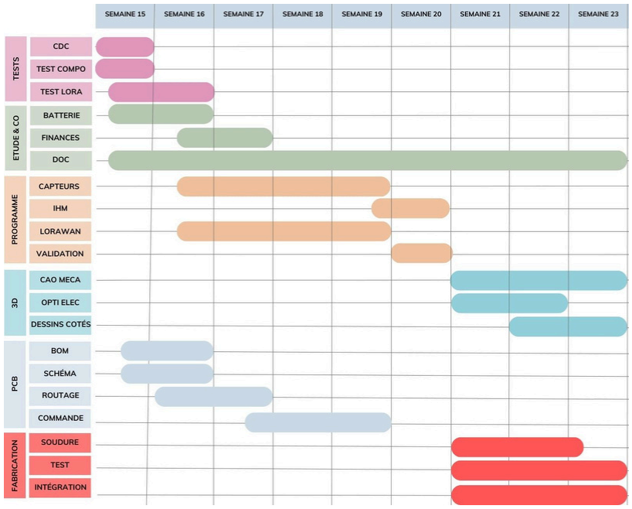
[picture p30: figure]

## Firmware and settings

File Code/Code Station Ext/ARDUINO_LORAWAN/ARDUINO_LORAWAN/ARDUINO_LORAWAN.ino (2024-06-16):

/* INCLUDE */

#include <STM32LoRaWAN.h>
#include <ArduinoJson.h>
#include "DHT.h"
#include "credential_ext.h"

/* DEFINE */
// Capteur Temp air
#define DHTPIN PA9      // Pin capteur temp air PA_12
#define DHTTYPE DHT11  // Définition du type de capteur temp air

#define PHPIN PB4  // Pin Sonde PH4

#define EAUPIN PA10 //Pin sonde de temperature d'eau

#define BTN_PRESS_PIN 11  // Pin numérique bouton d'envoi instantané de données

#define LED_COM_PIN 5  // Pin numérique pour la LED de communication (BLEU)

#define TdsSensorPin PB2  // Pin analogique sonde TDS
#define VREF 3.3          //  tension de référence analogique (Volt) de l'ADC
#define SCOUNT 30         // somme du nombre de points d'échantillonnage

/* CLASS */
STM32LoRaWAN modem;

/* VARIABLES */
// LoraWan
static const unsigned long TX_INTERVAL = 60000;  // Interval d'envoi en ms
unsigned long last_tx = 0;
DHT dht(DHTPIN, DHTTYPE);  // Intégration de la broche et du type

// Sonde PH
int samples = 10;
float adc_resolution = 1024.0;
String phInfo;

//sonde de température d'eau
String EauInfo;

// Bouton pression (envoi instantané de données)
bool buttonPressed = false;  // Variable pour suivre l'état du bouton

// Sonde TDS
int analogBuffer[SCOUNT];  // stocke la valeur analogique dans le tableau, lue depuis l'ADC
int analogBufferIndex = 0;
float averageVoltage = 0;
float tdsValue = 0;
float temperature = 25;  // température actuelle pour la compensation


/* Get the rtc object */
STM32RTC& rtc = STM32RTC::getInstance();

// permet de compter un nombre de periode de 100 ms
void compteur(int i){
  int a=0;
  while (a<i){
    unsigned long tempsDebut = millis(); // Définir le temps de départ
    while (millis() - tempsDebut < 98) {
      a+=1;
    }
  }
}


void setup() {

  /* Begin */
  Serial.begin(115200);
  Serial.println("Start");

  modem.begin(EU868);  // Config du modem
  dht.begin();         // Config du capteur temp air

  pinMode(BTN_PRESS_PIN, INPUT);  // Config de la broche bouton

  pinMode(LED_COM_PIN, OUTPUT);  // Config de la broche led com
  digitalWrite(LED_COM_PIN, LOW);

  pinMode(TdsSensorPin, INPUT);  // Config Sond TDS

  /* Lora Keys */
  bool connected = modem.joinOTAA(/* AppEui */ APPEUI, /* AppKey */ APPKEY, /* DevEui */ DEVEUI);
  //bool connected = modem.joinABP(/* DevAddr */ "00000000", /* NwkSKey */ "00000000000000000000000000000000", /* AppSKey */ "00000000000000000000000000000000");

  /* Jonction Lora */
  if (connected) {
    Serial.println("Joined");
  } else {
    Serial.println("Join failed");
    while (true) /* infinite loop */
      ;
  }
}

/* FONCTIONS */
// Envoi des données en Lora dans un JSON
void send_packet() {

  //Mesures nécessaires avant création de l'objet JSON
  ph_measure();
  TDS_measure();
  eau_measure();
  // Créer un objet JSON et récupération des données
  StaticJsonDocument<512> doc;
  doc["T_air"] = String(dht.readTemperature());
  doc["H_air"] = String(dht.readHumidity());
  doc["PH"] = phInfo;
  doc["TDS"] = String(tdsValue) + "ppm";
  doc["T_eau"] = EauInfo;


  // Sérialiser l'objet JSON en une chaîne de caractères
  String jsonStr;
  serializeJson(doc, jsonStr);

  // Préparer et envoyer le paquet LoRa
  modem.setPort(10);
  modem.beginPacket();
  modem.write(jsonStr.c_str(), jsonStr.length());
  if (modem.endPacket() == (int)jsonStr.length()) {
    Serial.println("Sent packet: " + jsonStr);

    digitalWrite(LED_COM_PIN, HIGH);  // Allumer la LED après un envoi réussi
    compteur(10);                      // Garder la LED allumée pendant 1 seconde
    digitalWrite(LED_COM_PIN, LOW);   // Éteindre la LED

  } else {
    Serial.println("Failed to send packet");
  }

  // Vérifier les messages downlink
  if (modem.available()) {
    Serial.print("Received packet on port ");
    Serial.print(modem.getDownlinkPort());
    Serial.print(":");
    while (modem.available()) {
      uint8_t b = modem.read();
      Serial.print(" ");
      Serial.print(b >> 4, HEX);
      Serial.print(b & 0xF, HEX);
    }
    Serial.println();
  }
}

float eau (float voltage1) {
    return ((voltage1*22.6)/250);
}
void eau_measure() {
    int measuring=0;

    for (int i = 0; i < samples; i++)
    {
        measuring += analogRead(EAUPIN);
        compteur(1);

    }
    float voltage1 = measuring/samples;
    EauInfo = String(eau(voltage1));
}

// Convertion PH
float ph(float voltage) {
  return 7 + ((2 - voltage) / 0.18);
}

// Mesure PH
void ph_measure() {
  int measurings = 0;
  for (int i = 0; i < samples; i++) {
    measurings += analogRead(PHPIN);
    compteur(1);
  }
  float voltage = 3.3 / adc_resolution * measurings / samples;
  phInfo = String(ph(voltage));
}

// Sonde TDS
int getMedianNum(int bArray[], int iFilterLen) {
  int bTab[iFilterLen];
  for (byte i = 0; i < iFilterLen; i++)
    bTab[i] = bArray[i];
  int i, j, bTemp;
  for (j = 0; j < iFilterLen - 1; j++) {
    for (i = 0; i < iFilterLen - j - 1; i++) {
      if (bTab[i] > bTab[i + 1]) {
        bTemp = bTab[i];
        bTab[i] = bTab[i + 1];
        bTab[i + 1] = bTemp;
      }
    }
  }
  // si la longueur du tableau est impair, retourner la valeur médiane
  if ((iFilterLen & 1) > 0) {
    bTemp = bTab[(iFilterLen - 1) / 2];
  } else {
    bTemp = (bTab[iFilterLen / 2] + bTab[iFilterLen / 2 - 1]) / 2;
  }
  return bTemp;
}

void TDS_measure() {
  for (int i =0;i<SCOUNT;i++){
    analogBuffer[i] = analogRead(TdsSensorPin);    // lire la valeur analogique et la stocker dans le tampon
  }
  // lire la valeur analogique de manière plus stable grâce à l'algorithme de filtrage médian, et la convertir en valeur de tension
  averageVoltage = getMedianNum(analogBuffer, SCOUNT) * (float)VREF / 4096.0;
  // formule de compensation de température : fFinalResult(25^C) = fFinalResult(current)/(1.0+0.02*(fTP-25.0));
  float compensationCoefficient = 1.0 + 0.02 * (temperature - 25.0);
  //temperature compensation
  float compensationVoltage = averageVoltage / compensationCoefficient;
  // convertir la valeur de tension en valeur de TDS
  tdsValue = (133.42 * compensationVoltage * compensationVoltage * compensationVoltage - 255.86 * compensationVoltage * compensationVoltage + 857.39 * compensationVoltage) * 0.5;
}

/* LOOP */
void loop() {
  /* Vérification de l'état du bouton */
  if (digitalRead(BTN_PRESS_PIN) == HIGH) {
    Serial.println("Bouton Pressé");
    send_packet();  // Envoyez les données immédiatement lorsque le bouton est pressé
    Serial.println("Envoi instantané effectué");
    while (digitalRead(BTN_PRESS_PIN) == HIGH)
      ;  // Attendre que le bouton soit relâché pour éviter les envois multiples
  }

  /* Cycle habituel d'envoi de données */
  if (!last_tx || millis() - last_tx > TX_INTERVAL) {
    send_packet();
    last_tx = millis();
  }
}

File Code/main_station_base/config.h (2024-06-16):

#include "credential.h"

//CONFIG
#define DEV 1 //1 if dev mode 0 production mode
#define BAUDRATE 115200
//The smaller the more accurate but the less battery life
#define PRECISON_CLOCK 5000 //in second


//Ecran TFT configuration
#define TFT_GREY 0x5AEB // Grey colour 
/* PIN ESP32  | PIN TFT
*       3,3V  | VCC 
*         GND | GND
*         D15 | CS
*          D4 | RESET
*          D2 | DC
*         D23 | MOSI
*         D18 | SCK
*       3,3V  | LED
*         D19 | MISO
*/

//Timer configuration
#define TIME_ZONE "CET-1CEST-2,M3.5.0/02:00:00,M10.5.0/03:00:00"; //Time zone for the clock
/*==== Planet widget ==== */
//Size to display
#define SIZE_SUN 20             //in pixel
#define SIZE_EARTH 10           //in pixel
#define SIZE_MOON 5             //in pixel
#define ORBIT_RADIU_EARTH 60    //in pixel
#define ORBIT_RADIU_MOON 20     //in pixel
//Define in how many days it will do the entire rotation
#define TEMPS_REVOLUTION_EARTH 365  //in days
#define TEMPS_REVOLUTION_MOON 27    //in days
//the center of the planet widget x
#define CENTER_PLANET_X 150     //in pixels
#define CENTER_PLANET_Y 90      //in pixels
//Define the angle for the 1 of january
#define ANGLE_OFFSET M_PI_2     //in radian 


/*==== weather widget ====*/
//The weather widget is a small widget that display the weather
#define CENTER_WEATHER_X 150   //in pixels
#define TOP_WEATHER_Y 220   //in pixels
//define the URL to request :
#define WEATHER_APIKEY WEATHER_TOKEN
//USING Open weather API USE THIS : 
#define OPEN_WEATHER 1
//USING meteo-concept (FRANCE ONLY !):
#define METEO_CONCEPT 0
//Complete the following : 
#if OPEN_WEATHER
  #define WEATHER_CITY "Angers"
  #define WEATHER_CONTRY "FR"
  #define URL_API "XXXX" WEATHER_CITY "," WEATHER_CONTRY "&units=metric&APPID=" WEATHER_APIKEY
#endif
#if METEO_CONCEPT
  #define INSEE "XXXXX"
  #define URL_API "XXXX" INSEE "&token=" WEATHER_APIKEY
#endif

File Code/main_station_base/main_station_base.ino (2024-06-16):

#include <WiFi.h>
#include <esp_wifi.h>
#include "time.h"
#include "sntp.h"
#include <TFT_eSPI.h> // Graphics and font library for ILI9341 driver chip
#include <SPI.h>
#include "WiFiClientSecure.h"
//#include "WiFiClient.h"
#include <PubSubClient.h>

//config
#include "config.h"
//wifi credential
#include "credential.h"
//time
#include "master_time.h"
//Screen
TFT_eSPI tft = TFT_eSPI();
//weather
#include "weather.h"
//butmap
#include "bitmaps.h"
//JSON
#include <Arduino_JSON.h>

WiFiClientSecure wifiClient;
//WiFiClient wifiClient;
PubSubClient mqttClient;
#define TOPIC_NAME "XXXXXXX"

#define PORT  XXXX
#define SIZE_BUFFER 2048
#define TOPIC_HUMIDITY "H_air"
#define TOPIC_PH "PH"
#define TOPIC_AIR "T_air"
#define TOPIC_EAU "T_eau"
#define TOPIC_TDS "TDS"

String H_air;
String PH;
String t_air;
String t_eau;
String tds;


//Save the last Time we pass the boucle
typedef struct{
  int second;
  int min;
  int hour;
  int day;
  int month;
}T;

// Update the last time recorded
void updateLastTime(T* lt,TimeM* t){
  lt->second = t->second;
  lt->min = t->min;
  lt->hour = t->hour;
  lt->day = t->day;
  lt->month = t->month;
}

#define BACKGROUND_COLOR TFT_WHITE
#define TEXT_COLOR TFT_BLACK

//Init object
TimeM timeM;
Weather weather;

// Prototypes for the scheduler functions
void each_5seconds(bool* refresh);
void each_30seconds(bool* refresh);
void each_mins(bool* refresh);
void each_hours(bool* refresh);
void each_days(bool* refresh);

const uint8_t MACAddress[] PROGMEM= {0xAC, 0x67, 0xB2, 0x2B, 0x7F, 0x20};

// Callback function for MQTT messages
void callback(char* topic, byte* payload, unsigned int length) {
  // Convert the payload to a string
  char message[length + 1];
  memcpy(message, payload, length);
  message[length] = '\0';

  // Print the received topic and message
  Serial.print("Message arrived [");
  Serial.print(topic);
  Serial.print("]: ");
  Serial.println(message);

  // Parser le JSON
  JSONVar myObject = JSON.parse(message);

  // Check if parsing was successful
  if (JSON.typeof(myObject) == "undefined") {
      Serial.println("Parsing JSON failed!");
      return;
  }

  // Access the "uplink_message" and "decoded_payload" sub-objects
  if (myObject.hasOwnProperty("uplink_message") && 
      myObject["uplink_message"].hasOwnProperty("decoded_payload")) {
      JSONVar decodedPayload = myObject["uplink_message"]["decoded_payload"];

      // Check for the presence of TOPIC_HUMIDITY
      if (decodedPayload.hasOwnProperty(TOPIC_HUMIDITY)) {
          H_air = (const char*)decodedPayload[TOPIC_HUMIDITY];
          Serial.print("Humidity: ");
          Serial.println(H_air);
      } 
      // Check for the presence of TOPIC_PH
      if (decodedPayload.hasOwnProperty(TOPIC_PH)) {
          PH = (const char*)decodedPayload[TOPIC_PH];
          Serial.print("PH: ");
          Serial.println(PH);
      }
      // Check for the presence of TOPIC_AIR
      if (decodedPayload.hasOwnProperty(TOPIC_AIR)) {
          t_air = (const char*)decodedPayload[TOPIC_AIR];
          Serial.print("t_air: ");
          Serial.println(t_air);
      }
      // Check for the presence of TOPIC_EAU
      if (decodedPayload.hasOwnProperty(TOPIC_EAU)) {
          t_eau = (const char*)decodedPayload[TOPIC_EAU];
          Serial.print("t_eau: ");
          Serial.println(t_eau);
      }
      // Check for the presence of TOPIC_TDS
      if (decodedPayload.hasOwnProperty(TOPIC_TDS)) {
          tds = (const char*)decodedPayload[TOPIC_TDS];
          Serial.print("tds: ");
          Serial.println(tds);
      }
  } else {
        Serial.println("decoded_payload not found in uplink_message.");
    }
}

// Reconnect to MQTT server
void reconnect(){
  if(!mqttClient.connected()){
    Serial.println("Connecting to MQTT...");
    mqttClient.connect("esp32_Neptune_Sense",USER_MQTT,PASS_MQTT);
    while (!mqttClient.connected()){
      Serial.print("Failed to connect to MQTT server, code: ");
      Serial.println(mqttClient.state());
      delay(1000);
    }
  Serial.println("Connected to MQTT server");
  }
}

void setup()
{
  SPI.setFrequency(5000000);
  //Set a fix mac adress
  esp_wifi_set_mac(WIFI_IF_STA, &MACAddress[0]);

  #if DEV
    Serial.begin(BAUDRATE);
    Serial.println("Starting setup...");

    //connect to WiFi
    Serial.print("ESP Board MAC Address:  ");
    Serial.println(WiFi.macAddress());
  #endif
  
  //Connect to wifi
  int attempt = 0;
  int cred = 0;
  int nb_credentials = sizeof(credentials)/sizeof(Credential);
  #if DEV
    Serial.printf("\nYou have : %d credentials to test.", nb_credentials);
  #endif
  
  WiFi.mode(WIFI_STA);

  do {
      if (!(attempt%10)){
        WiFi.begin(credentials[cred].ssid, (credentials[cred].password=="")?NULL:credentials[cred].password);
        #if DEV
          Serial.printf("\nConnecting to %s ", credentials[cred].ssid);
        #endif
        cred = (cred<nb_credentials-1)? cred+1:0 ;
      }
      delay(1000);
      attempt++;
      #if DEV
        Serial.print(".");
      #endif
  } while (WiFi.status() != WL_CONNECTED);
  
  #if DEV
    Serial.println(" CONNECTED");
    Serial.print("IP address: ");
    Serial.println(WiFi.localIP());
  #endif

  //Set wifi to use ssl certificate
  wifiClient.setInsecure();
  //Connect mqtt
  mqttClient.setClient(wifiClient);
  mqttClient.setServer(SERVER_MQTT, PORT);
  Serial.println("Set callback init");
  mqttClient.setCallback(callback);
  Serial.println("end callback init"); 
  mqttClient.setBufferSize(SIZE_BUFFER);
  reconnect();
  mqttClient.subscribe(TOPIC_NAME);  // Subscribe to the topic 
  

  //init servicies
  tft.init();
  tft.fillScreen(BACKGROUND_COLOR);
  weather.init();
  
  //init time
  int i = 1;
  timeM.init();
  while(!timeM.update_time()){
    #if DEV
    Serial.println("Initilizing time, attempt "+String(i));
    #endif
    i++;
    delay(500);
  }

  init_main();
  #if DEV
    Serial.println("Setup done");
  #endif
}
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
